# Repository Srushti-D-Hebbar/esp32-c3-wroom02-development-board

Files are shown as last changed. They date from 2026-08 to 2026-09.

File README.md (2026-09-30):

# ESP32-C3-WROOM-02 Development Board

A custom 4-layer development board built around the ESP32-C3-WROOM-02 module, designed from schematic to PCB using KiCad 10.

The board provides USB-C power and data connectivity, 3.3 V regulation, boot/reset controls, GPIO expansion, USB ESD protection, and an antenna keep-out region.

---
## Overview

This project covers the complete hardware design of a compact ESP32-C3 development board, from schematic design and component selection to multi-layer PCB layout and design-rule validation.

The board integrates:

- ESP32-C3-WROOM-02 module
- USB-C power and data interface
- 3.3 V regulated power supply
- USB ESD protection
- Boot and Reset buttons
- GPIO expansion headers
- External crystal oscillator
- Power filtering and decoupling
- 4-layer PCB
- Dedicated ESP32 antenna keep-out region

The schematic and PCB were designed using **KiCad 10**.

---
## Features

- ESP32-C3-WROOM-02 module
- USB-C power and USB data interface
- USB-UART interface
- 3.3 V LDO power supply
- USB ESD protection
- Boot and Reset buttons
- GPIO expansion headers
- External crystal oscillator
- Power supply filtering and decoupling
- 4-layer PCB
- Custom component placement and routing
- ESP32 antenna keep-out region
- DRC validated with 0 errors and 0 unconnected items

---
## Software Used

- **KiCad 10**

---
## Hardware Architecture

The design is divided into several functional blocks.

### Input Power & USB-C

The USB-C interface provides both power input and USB data connectivity.

Components include:

- USB-C receptacle
- USB power input
- USB D+ and D− data lines
- USB ESD protection
- CC resistors
- Power filtering capacitors

### 3.3 V Power Supply

The ESP32-C3 operates from a 3.3 V supply generated using an AP2112K-3.3 LDO.

Components include:

- AP2112K-3.3 LDO
- Input capacitor
- Output capacitor
- 3.3 V power rail

### ESP32-C3-WROOM-02

The main module provides the processing and wireless functionality of the board.

The design includes:

- ESP32-C3-WROOM-02
- Decoupling capacitors
- External crystal
- EN connection
- GPIO connections
- USB/UART connections
- Antenna keep-out region

### Boot & Reset

Dedicated push buttons are provided for:

- Boot mode selection
- Reset control

Pull-up resistors and RC components are used for the required control signals.

### GPIO Expansion

Two pin headers provide access to selected ESP32-C3 GPIO pins along with power and ground connections.

---
## Schematic

The schematic was designed in KiCad 10 and organized into functional blocks for power, USB-C, ESP32-C3, boot/reset, GPIO expansion, clock, and decoupling circuitry.

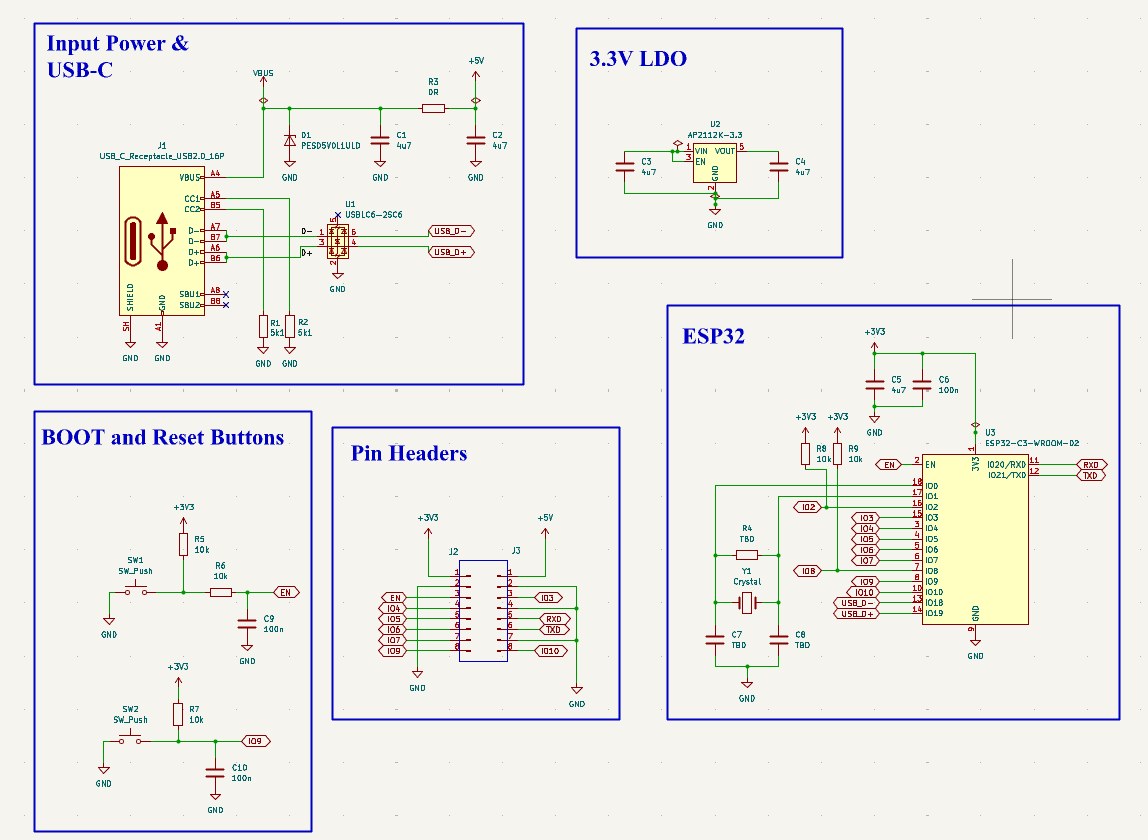
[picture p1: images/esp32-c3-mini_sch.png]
ESP32-C3-WROOM-02 Schematic


---
## PCB Design

The board uses a **4-layer PCB stackup** to provide additional routing flexibility and internal copper layers.

### PCB Stackup

| Physical Layer | KiCad Layer | Description |
|---|---|---|
| Layer 1 | F.Cu | Top copper |
| Layer 2 | In1.Cu | Inner copper layer 1 |
| Layer 3 | In2.Cu | Inner copper layer 2 |
| Layer 4 | B.Cu | Bottom copper |

---
## 3D Views

### Front View

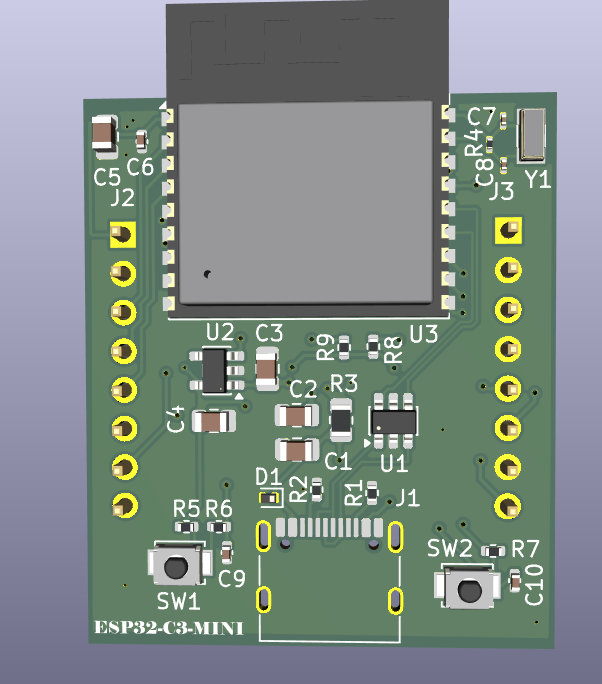
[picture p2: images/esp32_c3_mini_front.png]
3D Front View


The front 3D view showing the ESP32-C3-WROOM-02 module, USB-C interface, GPIO headers, buttons, and other components.

### Back View

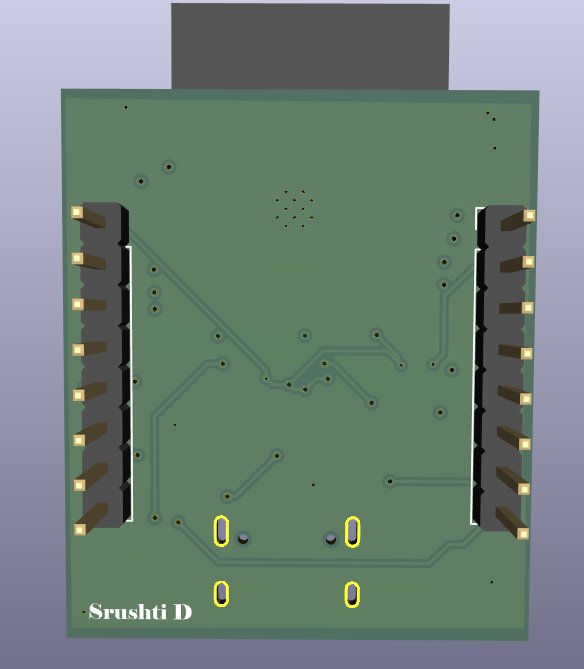
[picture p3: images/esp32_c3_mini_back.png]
3D Back View


The back 3D view showing the bottom side of the PCB and its components.

---
## Copper Layer Layout

### Front Copper — F.Cu

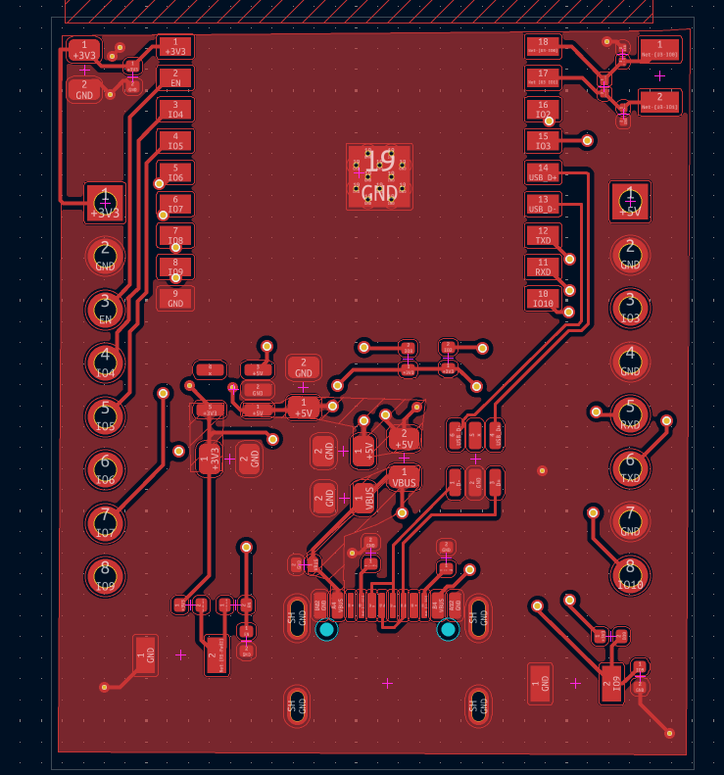
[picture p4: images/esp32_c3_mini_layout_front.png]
Front Copper Layer


The top copper layer showing component-side routing and copper distribution.

### Inner Copper Layer 1 — In1.Cu

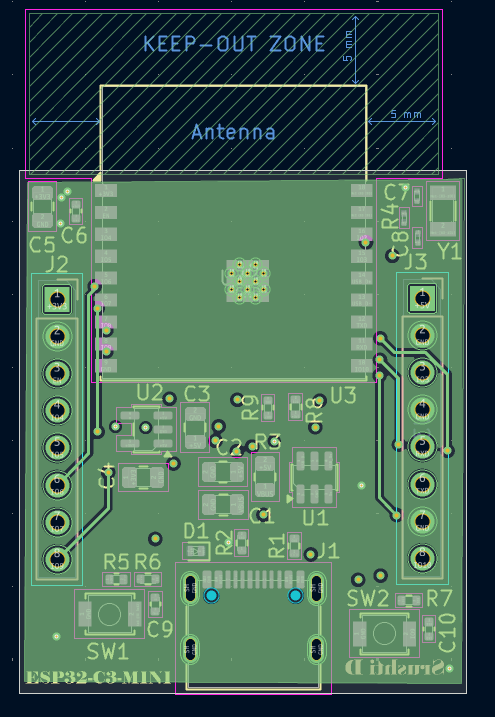
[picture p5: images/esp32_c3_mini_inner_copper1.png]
Inner Copper Layer 1


The first internal copper layer of the 4-layer PCB, showing the copper distribution and routing on `In1.Cu`.

### Inner Copper Layer 2 — In2.Cu

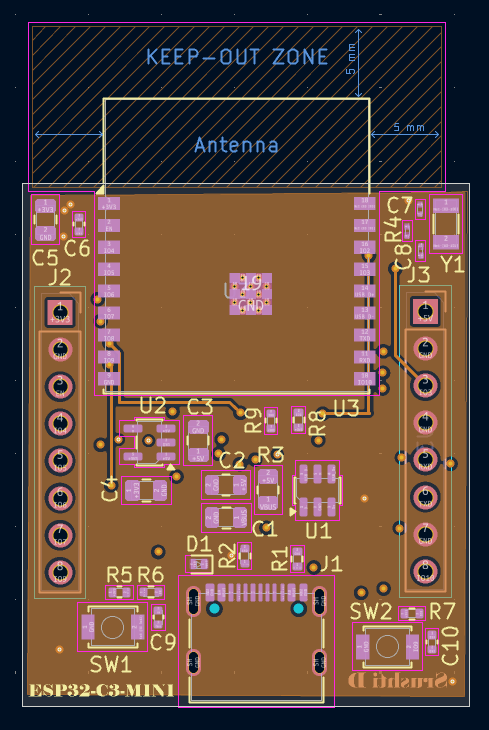
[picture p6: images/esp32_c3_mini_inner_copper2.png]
Inner Copper Layer 2


The second internal copper layer of the 4-layer PCB, showing the copper distribution and routing on `In2.Cu`.

### Back Copper — B.Cu

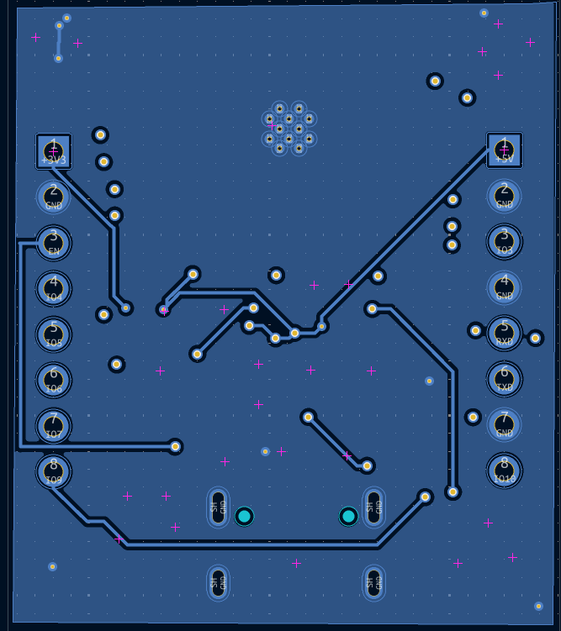
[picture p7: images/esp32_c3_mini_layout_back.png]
Back Copper Layer


The bottom copper layer showing the bottom-side routing and copper distribution.

---
## Antenna Keep-Out

A dedicated keep-out region is maintained around the ESP32-C3-WROOM-02 antenna.

The antenna area is kept clear of copper and other conductive structures to maintain the required clearance around the RF antenna region.

---
## PCB Specifications

| Parameter | Value |
|---|---|
| PCB Layers | 4 |
| Board Size | ~30.58 × 35.83 mm |
| PCB Thickness | 1.0 mm |
| Design Tool | KiCad 10 |
| Main Module | ESP32-C3-WROOM-02 |
| Logic Voltage | 3.3 V |
| USB Interface | USB-C |
| Power Regulator | AP2112K-3.3 |

---
## Main Components

- ESP32-C3-WROOM-02
- AP2112K-3.3 LDO
- USB-C connector
- USB-UART interface
- USBLC6-2SC6 USB ESD protection
- PESD5V0L1UL ESD protection diode
- Crystal oscillator
- Boot and Reset push buttons
- GPIO headers
- Decoupling and filtering capacitors
- Pull-up and configuration resistors

---
## Design Considerations

### 4-Layer PCB

A 4-layer PCB was used to provide additional routing flexibility and allow internal copper layers to be used for power, ground, and signal distribution as required by the design.

### USB Protection

ESD protection components are included on the USB interface to help protect the USB data lines from electrostatic discharge.

### Power Decoupling

Decoupling and filtering capacitors are placed around the power circuitry and ESP32-C3 module to support stable operation of the 3.3 V supply.

### Antenna Keep-Out

A dedicated copper keep-out region is provided around the ESP32-C3-WROOM-02 antenna area.

The keep-out extends around the antenna region to maintain clearance from surrounding copper and conductive structures.

### Component Placement

Component placement was carried out with consideration for:

- Short power connections
- Decoupling capacitor placement
- USB signal routing
- GPIO accessibility
- Antenna clearance
- Board compactness

---
## Design Validation

The completed PCB was checked using KiCad's Design Rules Checker (DRC).

- **DRC errors:** 0
- **Unconnected items:** 0

The design was reviewed for routing connectivity and PCB design-rule compliance.

---
## Learning Outcomes

This project provided hands-on experience with:

- 4-layer PCB design
- PCB stackup planning
- Schematic design
- Functional block partitioning
- ESP32-C3 hardware design
- USB-C power and data interface design
- USB ESD protection
- 3.3 V power regulation
- Power filtering and decoupling
- RF antenna keep-out considerations
- Component placement
- Multi-layer PCB routing
- KiCad DRC and design validation
- Preparing a PCB design for fabrication

---
## Future Improvements

Possible future improvements include:

- Add automatic Boot/Reset circuitry for easier programming
- Add power and status indicator LEDs
- Add a battery charging circuit
- Explore a smaller board footprint
- Add additional peripheral interfaces
- Add mounting holes
- Further optimize the PCB layout for compactness

---
## License

This project is licensed under the MIT License — see the [LICENSE](https://claude.ai/chat/LICENSE) file for details.

---
## Author

**Srushti D Hebbar** [GitHub](https://github.com/Srushti-D-Hebbar)

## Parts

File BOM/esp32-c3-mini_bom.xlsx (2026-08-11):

Id | Designator | Footprint | Quantity | Designation | Supplier and ref
1 | C1, C2, C3, C4, C5 | C_0805_2012Metric | 5 | 4u7
2 | C6, C9, C10 | C_0402_1005Metric | 3 | 100n
3 | C7, C8 | C_0201_0603Metric | 2 | TBD
4 | D1 | D_SOD-882D | 1 | PESD5V0L1UL
5 | J1 | USB_C_Receptacle_G-Switch_GT-USB-7010ASV | 1 | USB-C
6 | J2, J3 | PinHeader_1x08_P2.54mm_Vertical | 2 | 8-pin header
7 | R1, R2 | R_0402_1005Metric | 2 | 5k1
8 | R3 | R_0805_2012Metric | 1 | 0R
9 | R4 | R_0201_0603Metric | 1 | TBD
10 | R5, R7, R8, R9 | R_0402_1005Metric | 4 | 10k
11 | R6 | R_0402_1005Metric | 1 | 100k
12 | SW1, SW2 | SW_SPST_B3U-1000P | 2 | Push Button
13 | U1 | SOT-23-6 | 1 | USB-UART IC
14 | U2 | SOT-23-5 | 1 | AP2112K-3.3
15 | U3 | ESP32-C3-WROOM-02 | 1 | ESP32-C3-WROOM-02
16 | Y1 | Crystal_SMD_3215-2Pin_3.2x1.5mm | 1 | Crystal

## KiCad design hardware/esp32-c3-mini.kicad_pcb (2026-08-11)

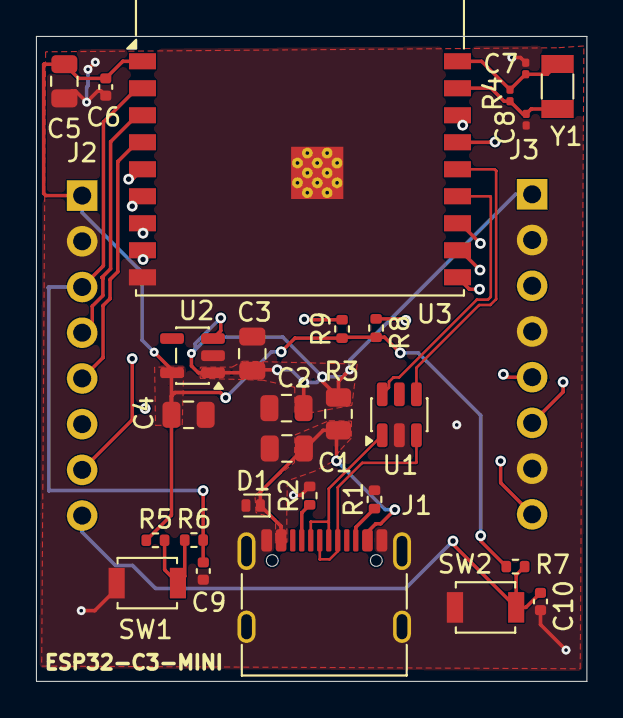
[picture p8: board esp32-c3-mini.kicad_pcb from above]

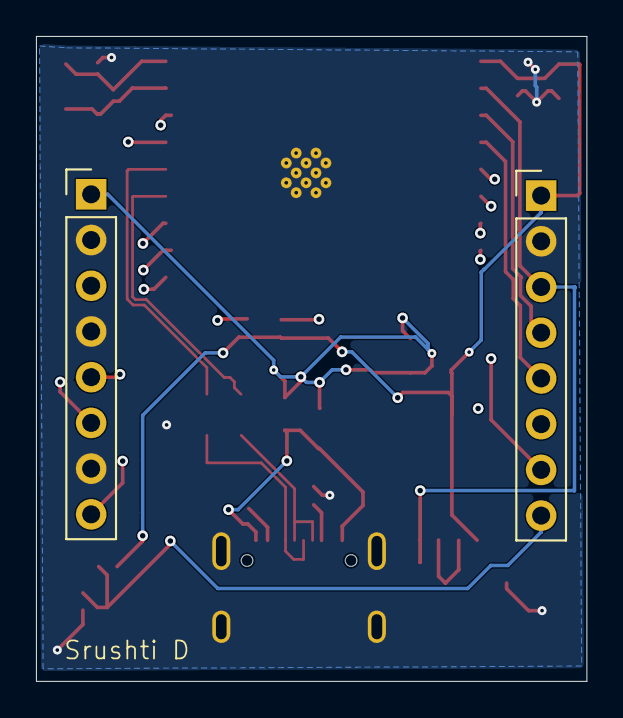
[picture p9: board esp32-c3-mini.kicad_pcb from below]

Board: 4 copper layers, 30.6 x 35.8 mm, 29 parts (2 on the bottom side), 25 nets.

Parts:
C1, C2, C3, C4, C5: 4u7; C_0805_2012Metric
C6, C9, C10: 100n; C_0402_1005Metric
C7, C8: TBD; C_0201_0603Metric
D1: PESD5V0L1UL; D_SOD-882D
J1: USB-C; USB_C_Receptacle_G-Switch_GT-USB-7010ASV
J2, J3: 8-pin header; PinHeader_1x08_P2.54mm_Vertical
R1, R2: 5k1; R_0402_1005Metric
R3: 0R; R_0805_2012Metric
R4: TBD; R_0201_0603Metric
R5, R7, R8, R9: 10k; R_0402_1005Metric
R6: 100k; R_0402_1005Metric
SW1, SW2: Push Button; SW_SPST_B3U-1000P
U1: USB-UART IC; SOT-23-6
U2: AP2112K-3.3; SOT-23-5
U3: ESP32-C3-WROOM-02
Y1: Crystal; Crystal_SMD_3215-2Pin_3.2x1.5mm

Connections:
+3V3: C4.1, C5.1, C6.1, J2.1, R5.1, R7.1, R8.1, R9.1, U2.5 (VOUT), U3.1 (3V3)
+5V: C2.1, C3.1, J3.1, R3.2, U2.1 (VIN), U2.3 (EN)
/ESP32-C3-MINI/D+: J1.A6 (D+), J1.B6 (D+), U1.3 (I/O2)
/ESP32-C3-MINI/D-: J1.A7 (D-), J1.B7 (D-), U1.1 (I/O1)
EN: C9.1, J2.3, R6.2, U3.2 (EN)
GND: C1.2, C2.2, C3.2, C4.2, C5.2, C6.2, C7.2, C8.2, C9.2, C10.2, D1.2 (A), J1.A1 (GND), J1.A12 (GND), J1.B1 (GND), J1.B12 (GND), J1.SH (SHIELD), J2.2, J3.2, J3.4, J3.7, R1.2, R2.2, SW1.1, SW2.1, U1.2 (GND), U2.2 (GND), U3.9 (GND), U3.19 (GND)
IO2: R8.2, U3.16 (IO2)
IO3: J3.3, U3.15 (IO3)
IO4: J2.4, U3.3 (IO4)
IO5: J2.5, U3.4 (IO5)
IO6: J2.6, U3.5 (IO6)
IO7: J2.7, U3.6 (IO7)
IO8: R9.2, U3.7 (IO8)
IO9: C10.1, J2.8, R7.2, SW2.2, U3.8 (IO9)
IO10: J3.8, U3.10 (IO10)
unnamed: J1.A5 (CC1), R2.1
unnamed: J1.B5 (CC2), R1.1
unnamed: R5.2, R6.1, SW1.2
unnamed: C7.1, R4.1, U3.18 (IO0), Y1.1
unnamed: C8.1, R4.2, U3.17 (IO1), Y1.2
RXD: J3.5, U3.11 (IO20/RXD)
TXD: J3.6, U3.12 (IO21/TXD)
USB_D+: U1.4 (I/O2), U3.14 (IO19)
USB_D-: U1.6 (I/O1), U3.13 (IO18)
VBUS: C1.1, D1.1 (K), J1.A4 (VBUS), J1.A9 (VBUS), J1.B4 (VBUS), J1.B9 (VBUS), R3.1
